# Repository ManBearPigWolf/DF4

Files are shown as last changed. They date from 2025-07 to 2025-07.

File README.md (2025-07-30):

# DF4
Open source LAB DF3 clone, but with a face insert.

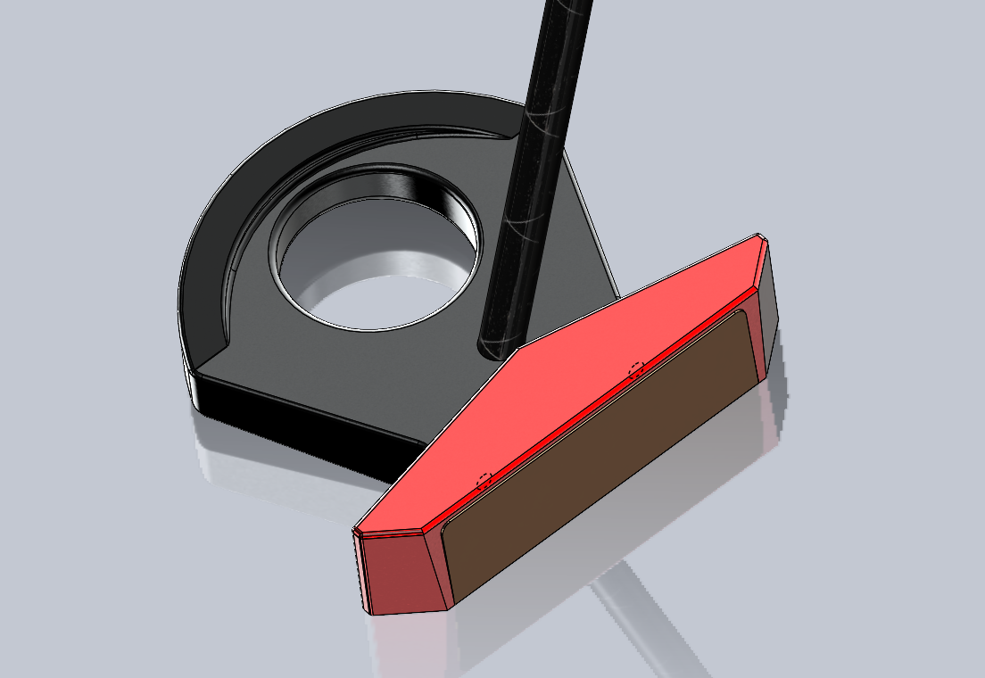
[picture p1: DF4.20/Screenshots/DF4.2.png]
Putter Assembly

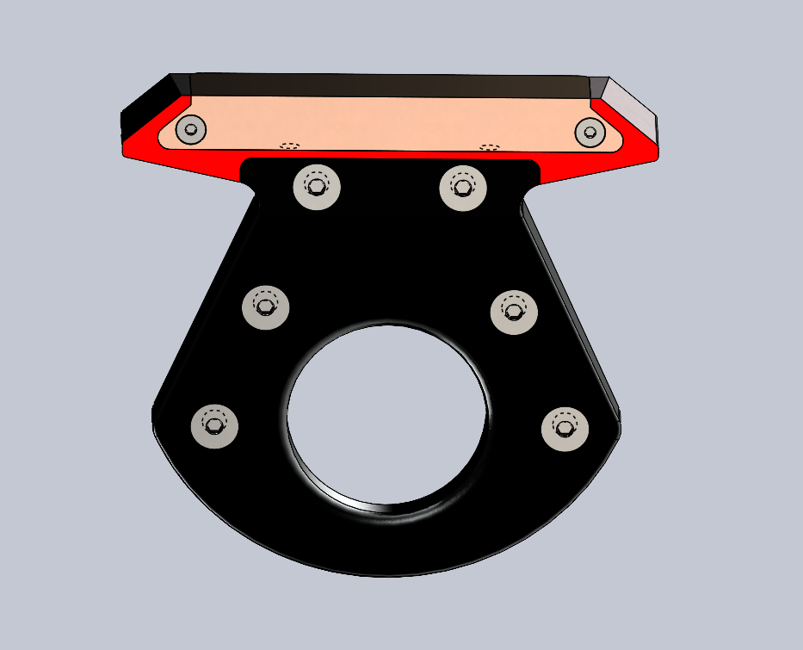
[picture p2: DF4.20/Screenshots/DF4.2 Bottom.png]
Putter Bottom

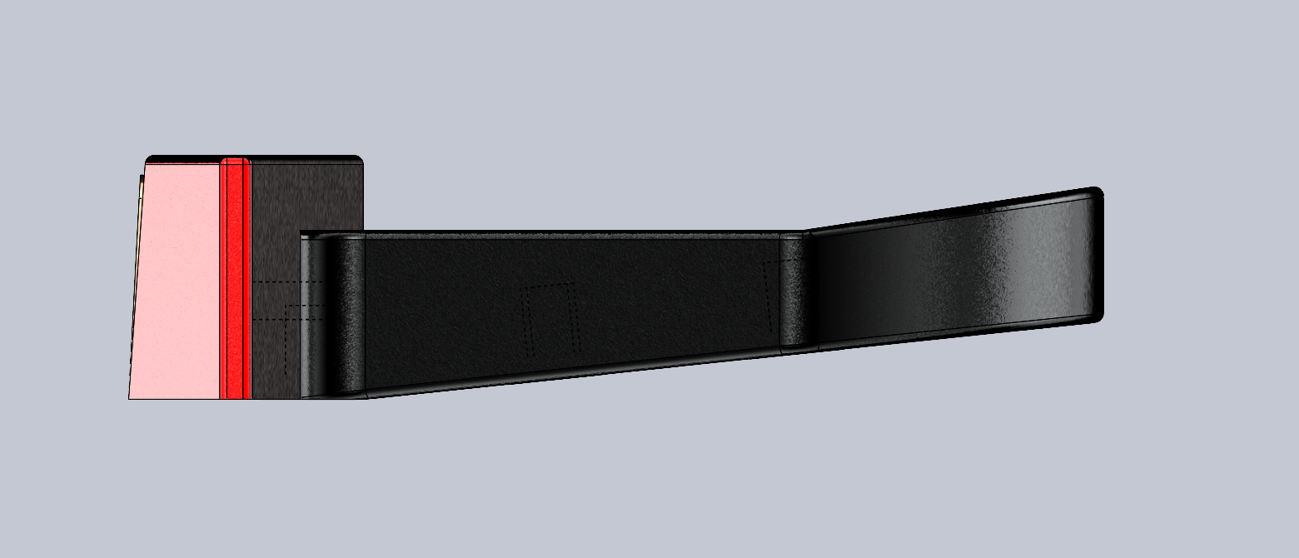
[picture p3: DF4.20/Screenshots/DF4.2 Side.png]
Putter Side

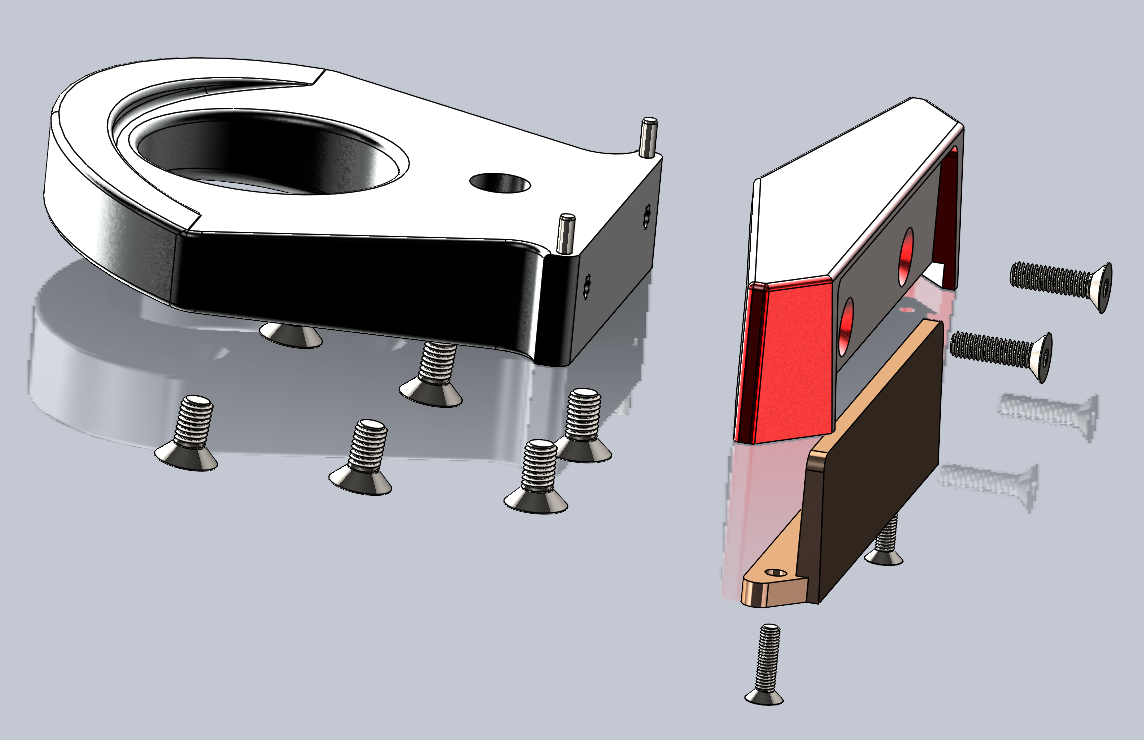
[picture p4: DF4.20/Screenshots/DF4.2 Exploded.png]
Putter Explodeded

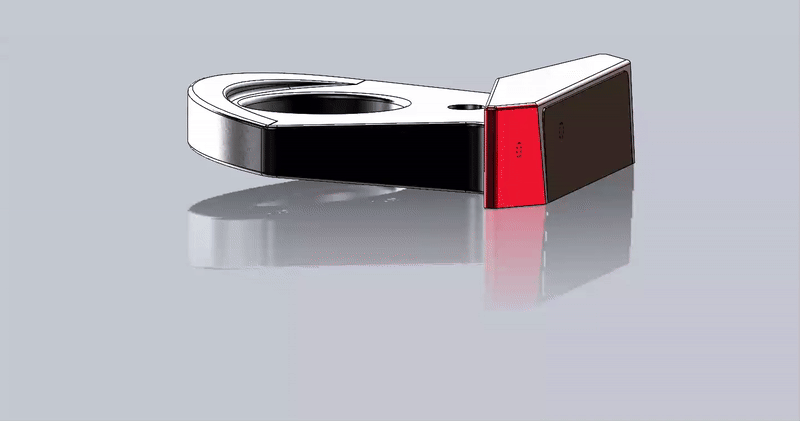
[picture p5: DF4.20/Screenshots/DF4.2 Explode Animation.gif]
Explode Animation


This is my attempt to clone a DF3 but with changes I think are useful. In all my putters, personalization and customization are core design principles.

The biggest change is the addition of a face insert. The insert is mechanically attached, ~~unlike the insert on the OZ1i which is glued on.~~ (Turns out the OZ1i intsert is screwed in from the back) There's nothing inherently wrong with gluing on inserts, almost all putters on the market with inserts use a glued attachment; my background as an engineer has always taught me to never make something permananet that doesn't need to be.

The second notable change is that the "body" of the putter and the piece that holds the face insert are two different parts. They use 3/32" dowel pins to make a locating attachment, and M4 flat head screws behind the face insert to make the secure mechanical attachment.

Separting the two pieces makes the manufacturing a little easier, as both parts have some pretty complicated geometry. Manufacturing as one piece would be quite a bit more difficult than two pieces that can be mated together. It also allows for easier customization of colors and sight lines, as well as potentially being able to swap shafts and lie angles without getting an entirely new putter.

For the hardware, if you look at the main folder of the project there are models of the screws and dowel pins used. The beginning of the file name is the partnumber you'd order from McMaster-Carr. You obviously don't need to order screws from McMaster, it's just where I get hardware models from. You'd also need various length of the M5 weight screws to do the final balancing. I had to use longer ones in the heel and shorter ones in the toe side, but you're putter will be made different and have a different shaft so there's no way to predict the exact screws you'll need.

--------------UPDATE 7/30----------------
I recieved the prototype of the DF4 yesterday, the pieces fit together flawlessly! I still need to balance it as it's slightly toe heavy, but this is to be expected. There's tolerances in machining and the shaft probably isn't exactly at 73 degrees, after stacking all the tolerances it's not reasonable to expect it to balance in a revealer without some weighting. I've uploaded a bunch of lie angles in left and right hand models so people can fit the putter to themselves. If there's something missing, just open an issue and I'll get it resolved as quickly as possible.

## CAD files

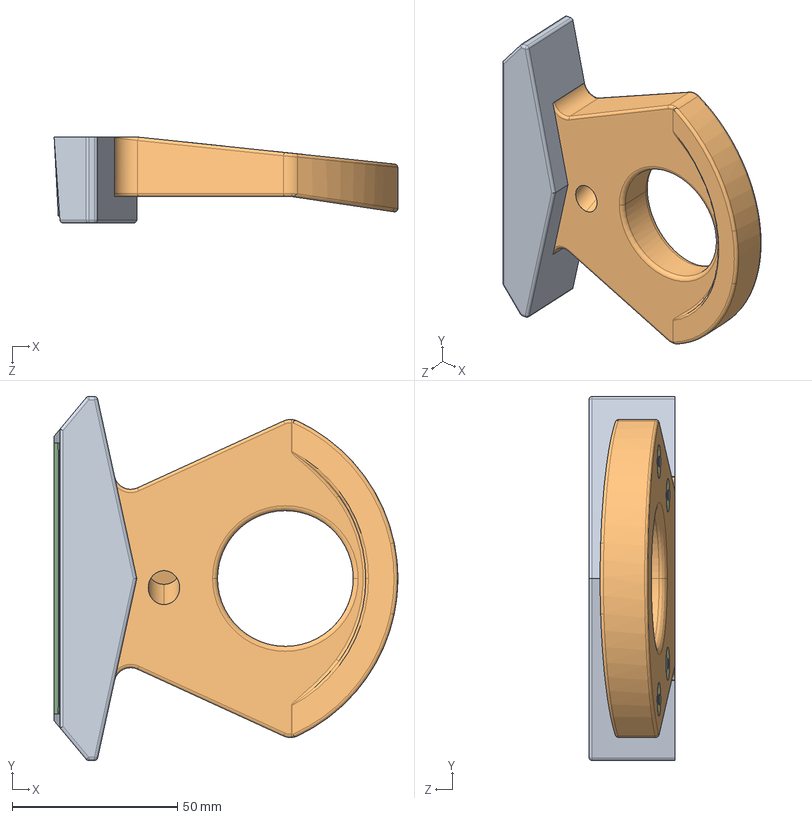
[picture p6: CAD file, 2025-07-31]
DF4.20/STEP Files/DF4.2 Assembly.STEP
103.9 x 110.0 x 26.0 mm
Head
98381A438_Dowel Pin_98381A438 x 2
DF Face Insert
92125A132_M3x12_92125A132 x 2
92125A104_M4x15_92125A104 x 2
93395A301_M5x10_93395A301 x 6

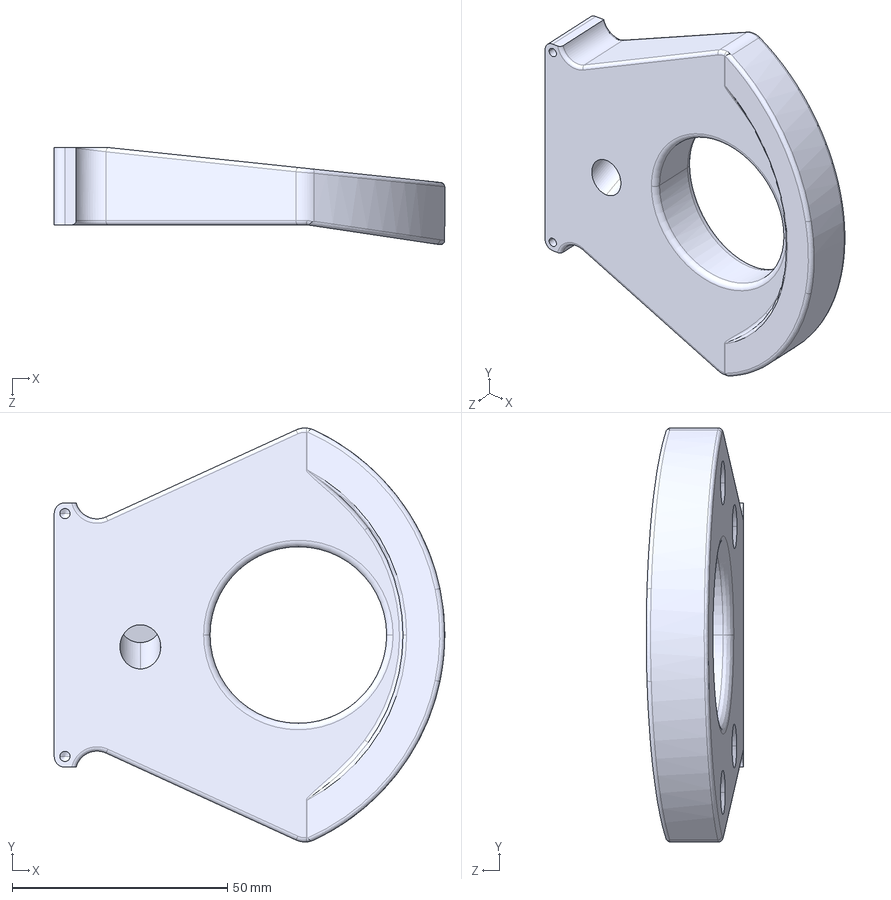
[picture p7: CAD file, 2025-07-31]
DF4.20/STEP Files/DF Head - 68 deg.STEP
90.7 x 96.1 x 22.6 mm

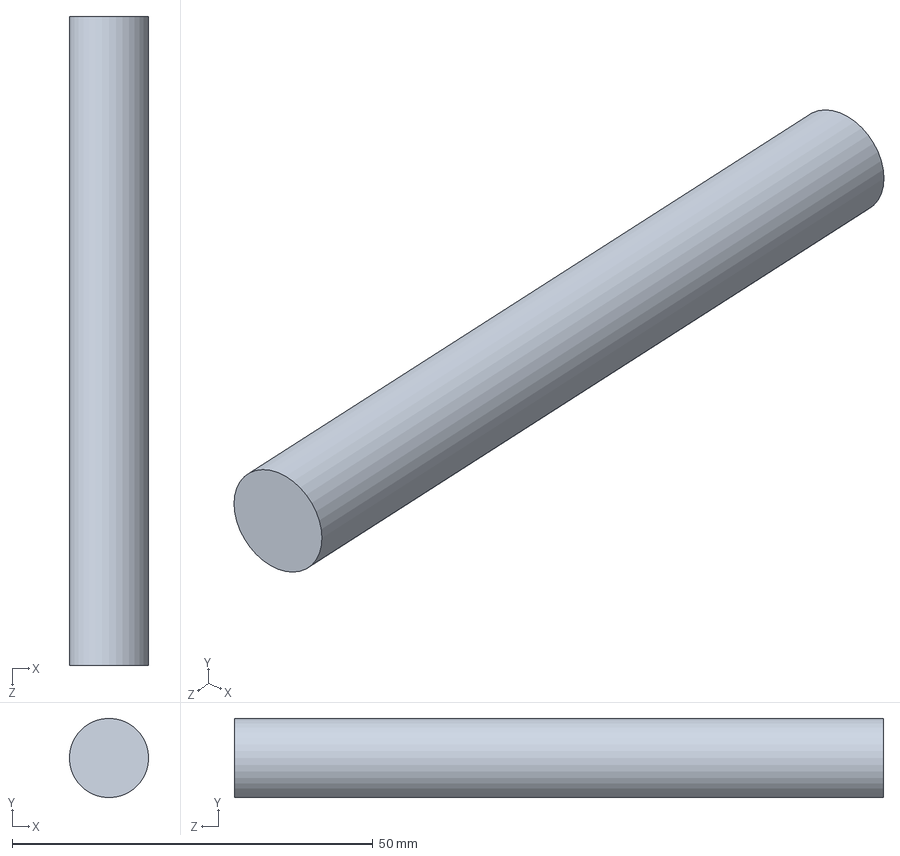
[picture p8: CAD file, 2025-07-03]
DF4.20/weight.SLDPRT
11.0 x 11.0 x 90.0 mm

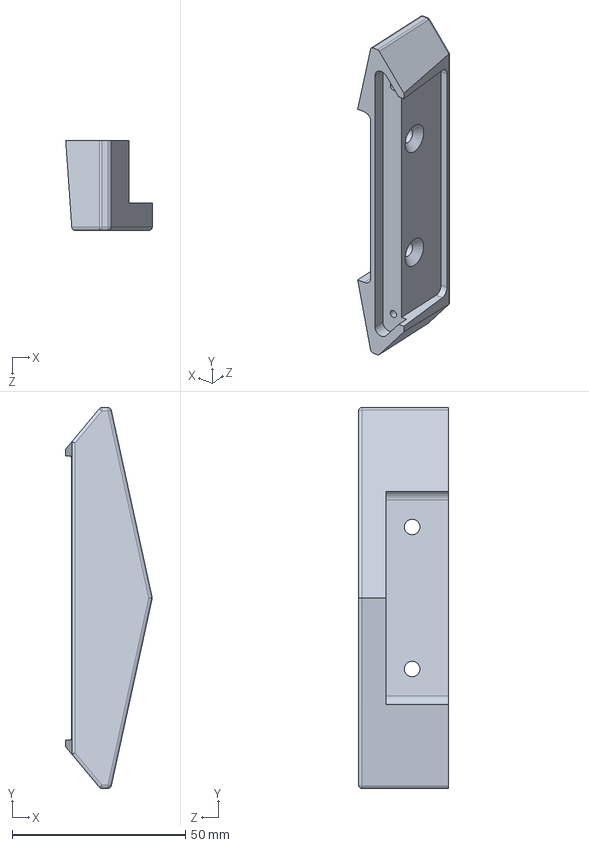
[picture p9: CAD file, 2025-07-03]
DF4.20/Face.SLDPRT
25.0 x 110.0 x 26.0 mm

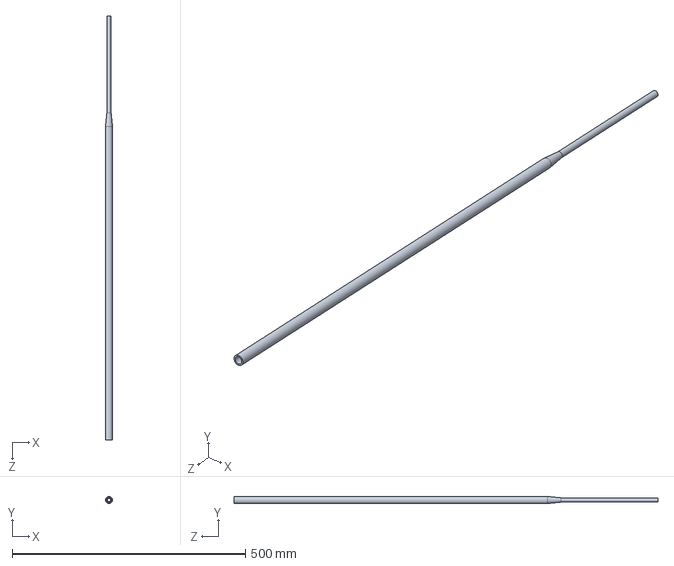
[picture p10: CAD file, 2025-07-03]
DF4.20/Stability Shaft.SLDPRT
15.2 x 15.2 x 908.0 mm

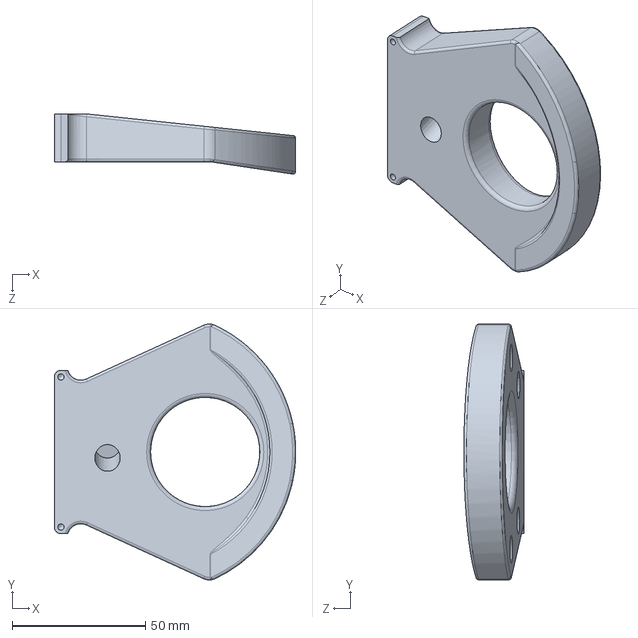
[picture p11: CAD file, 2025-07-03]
DF4.20/Head.SLDPRT
90.7 x 96.1 x 22.6 mm

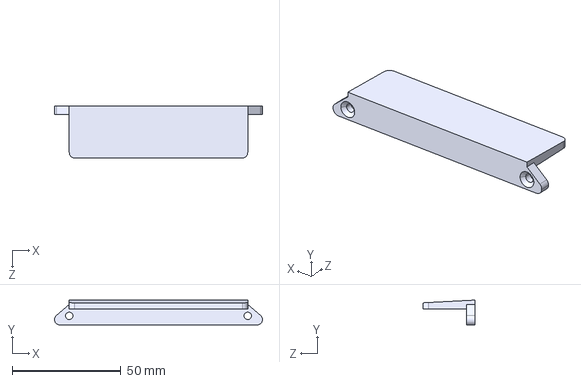
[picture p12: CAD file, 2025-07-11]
DF4.20/STEP Files/DF Face Insert - 3 deg loft.STEP
95.4 x 11.4 x 23.9 mm

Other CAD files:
DF4.20/STEP Files/DF Head - 70 deg - 2 deg shaft lean.STEP
DF4.20/STEP Files/DF Head - 72 deg - LEFTY.STEP
DF4.20/STEP Files/DF Head - 71 deg - LEFTY.STEP
DF4.20/STEP Files/DF Head - 70 deg.STEP
DF4.20/STEP Files/DF Head - 71 deg.STEP
DF4.20/STEP Files/DF Head - 72 deg.STEP
DF4.20/STEP Files/DF Head - 70 deg - LEFTY.STEP
DF4.20/STEP Files/DF Head - 73 deg - LEFTY.STEP
DF4.20/STEP Files/DF Head - 73 deg.STEP
DF4.20/STEP Files/DF Face Insert.STEP
DF4.20/STEP Files/DF Face.STEP
DF4.20/92125A104_M4x15.SLDPRT
DF4.20/92125A132_M3x12.SLDPRT
DF4.20/93395A301_M5x10.SLDPRT
DF4.20/98381A438_Dowel Pin.SLDPRT
DF4.20/DF Face Insert.SLDPRT
DF4.20/DF4.2 Assembly.SLDASM
